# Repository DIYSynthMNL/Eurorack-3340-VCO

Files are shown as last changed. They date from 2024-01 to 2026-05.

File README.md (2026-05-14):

# Eurorack-3340-VCO

A Eurorack VCO module based on the [AS3340](https://electricdruid.net/product/as3340-vco/) chip from Electric Druid — a drop-in clone of the classic Curtis CEM3340. Analog 1V/oct tracking with simultaneous saw, triangle, sine, and pulse outputs.

## Features

- **1V/oct tracking** with two summed V/oct CV inputs (use both for transpose/unison)
- **Course tune** with jumper-selectable range (narrow / wide via JP1) plus **Fine tune** pot
- **Linear FM input** with attenuator pot (Lin FM, ±5V CV)
- **PWM input** with amount attenuator (±5V CV), feeds the chip's pulse-width modulator
- **Hard / Soft Sync** input with panel switch for selection (AC-coupled, 1 nF)
- **Four simultaneous outputs (10 Vpp)**: Saw, Triangle, Sine (diode-shaped from triangle), Pulse
- **Three calibration trims**:
  - Scale trim (RV1) — V/oct gain
  - High-Frequency Tracking trim (RV7) — accuracy at high notes
  - Sine amplitude trim (RV6) — tri-to-sine shape
- **Polystyrene timing capacitor** (C8, 1 nF) for low temperature drift
- Eurorack ±12V power via either 16-pin IDC or 3-pin JST connector

## Inputs and outputs

| Jack | Range | Notes |
|---|---|---|
| V/oct 1 | ±5V | Summed with V/oct 2 at the frequency-control node |
| V/oct 2 | ±5V | Summed with V/oct 1; direct (no attenuator) |
| Lin FM | ±5V | Through RV2 attenuator pot, AC-coupled into chip's Linear FM input |
| PWM | ±5V | Through RV3 amount pot, scaled to ~0–5V into chip's PWM-In |
| Sync | gate/audio | AC-coupled (1 nF), SW1 routes to Hard Sync (down) or Soft Sync (up) |
| Saw Out | 10 Vpp | Buffered, 1K series, ±5V swing |
| Tri Out | 10 Vpp | Buffered, 1K series, ±5V swing |
| Sine Out | 10 Vpp | Diode tri-to-sine shaper, amplitude trim, buffered |
| Pulse Out | 10 Vpp | Buffered, 1K series, ±5V swing |

## Block diagram

```
   V/oct 1 ─┐
   V/oct 2 ─┼──[summing node, 10K + 10K + 47K (course) + 1M5 (fine)]─► AS3340 Freq Control
   Course  ─┤                                                        ├─► Saw    ─► [×2.09 buffer] ─► Saw Out
   Fine ────┘                                                        ├─► Tri    ─► [×2.09 buffer] ─► Tri Out
                                                                     │                          └► [diode shaper + RV6 amp trim] ─► Sine Out
   Lin FM ─► [×RV2 amount] ─► [bias network: 1M5/+12V, 470R/GND] ──► AS3340 Lin FM In           
                                                                     │
   PWM CV ─► [×RV3 amount + 100K/200K/100K conditioner] ───────────► AS3340 PWM In ◄─── [10K hysteresis from Pulse Out]
                                                                     │
   Sync in ─► [1 nF AC-couple] ─► SW1 ─► Hard Sync / Soft Sync ────► AS3340 Sync
                                                                     │
                                                                     └─► Pulse  ─► [×2.09 buffer] ─► Pulse Out

   Calibration trims:
     RV1 (Scale)  → AS3340 Scale1/Scale2 pins (V/oct gain)
     RV7 (HFT)    → AS3340 HFT pin (high-frequency correction)
     RV6 (Sine Amp) → tri-to-sine output buffer (sine amplitude)

   Eurorack ±12V ─► U3 (78M05) / U4 (79M05) ─► ±5V rails (op-amp + chip VEE)
   Timing cap: C8 = 1 nF polystyrene (critical: do not substitute ceramic)
```

## Power

- Eurorack ±12V via **J10** (3-pin JST) or **J11** (16-pin IDC) — populate one
- Local U3 (78M05) makes +5V from +12V
- Local U4 (79M05) makes −5V from −12V; this becomes the AS3340's VEE pin voltage
- R39 / R40 (10K) are optional minimum-load resistors
- D3 / D4 — reverse-polarity protection diodes

**AS3340 VEE protection.** The chip has an internal 7.4V Zener; the absolute max for VEE-to-GND is −6V. Because VEE here is driven from −5V (not −12V directly), no current-limiting resistor (REE) is needed.

If you ever modify the design to feed VEE directly from a more-negative rail, the datasheet formula is **REE = (|VEE| − 7.4) / 0.008**:

| VEE supply | REE |
|---|---|
| −5V | none |
| −12V | ~575 Ω |
| −15V | ~950 Ω (820 Ω works) |

## Calibration

The board has three trim pots that interact. Adjust in this order. You'll need: a multimeter, a frequency counter or tuner (a phone tuner app works), and a stable temperature environment (let the module warm up ~10 minutes first — the chip drifts thermally during warm-up).

**Step 1 — Scale trim (RV1).** Sets the V/oct gain. This is the most important trim for musical accuracy.

1. With no CV patched and Course/Fine at 12 o'clock, note the output frequency.
2. Patch a known reference voltage into V/oct 1 (e.g., 0V from a calibrated source or shorted to GND). Tune Course/Fine until the saw output matches a reference note — say C2 (65.41 Hz).
3. Apply +1V to V/oct 1. The output should rise exactly one octave (C3 = 130.81 Hz). If it's high, lower RV1 slightly; if low, raise it.
4. Step the input voltage up to +4V or +5V and verify the output is still tracking 1V/oct. Iterate RV1 + the tune knob until accurate across 5+ octaves.

**Step 2 — High-Frequency Tracking trim (RV7).** Compensates for internal comparator delay at very high notes.

1. With the V/oct calibrated (Step 1), apply +6V or +7V to push the output to ~8 kHz+.
2. Compare actual output frequency to expected (e.g., from 65.41 Hz baseline, +7 octaves = 8372 Hz).
3. Adjust RV7 to correct the deviation. RV7 mostly affects high frequencies — it should not noticeably shift low-frequency tuning.
4. Re-verify Step 1 calibration. If low-frequency tracking shifted, iterate.

**Step 3 — Sine Amplitude trim (RV6).** Sets the tri-to-sine shape and amplitude.

1. Patch a scope on the Sine Out jack with a steady tone (e.g., A4 = 440 Hz).
2. Adjust RV6 until the waveform looks like a clean sine — not too peaked (under-trimmed) and not flat-topped (over-trimmed).
3. By ear: clean smooth fundamental, no harsh harmonics.

## References

Local archived copies live in [`references/`](references/) so this repo stays useful if the upstream links die.

- **AS3340 datasheet** — [local copy](references/AS3340-alfatriode-2020.pdf) · [upstream (alfatriode.lv)](https://alfatriode.lv/eng/sc/AS3340.pdf)
- **Kassutronics 3340 VCO docs (v2.4)** — [local copy](references/Kassutronics-VCO3340-docs-v2.4.pdf) · [upstream (GitHub)](https://github.com/kassu/kassutronics/tree/master/documentation/VCO%203340) — primary design inspiration
- [Electric Druid AS3340 product page](https://electricdruid.net/product/as3340-vco/)
- [Electric Druid CEM3340 VCO designs](https://electricdruid.net/cem3340-vco-voltage-controlled-oscillator-designs/)
- [YuSynth VCO](https://yusynth.net/Modular/EN/VCO/index.html)
- [Tri-to-sine shaping techniques (Tim Stinchcombe)](https://www.timstinchcombe.co.uk/index.php?pge=trisin)

## Build status

What's ready for builders today, and what's still on the TODO list:

**Production assets** (what you need to actually fabricate and assemble a final unit)

- [x] Schematic — Rev 0.1.2 ([PDF](Schematic%20PDFs/3340-VCO-Schematic-Rev0.1.2.pdf))
- [ ] PCB layout — in progress — single working layout in `kicad/`, not yet separated for fab. The current rev is labeled "Prototype."
- [ ] Gerber files for fabrication — none yet
- [x] BOM — [Rev 0.1.0 PDF](BOMs/BOMs%20-%203340%20VCO%20-%20Schematic%20Rev%200.1.0.pdf) *(critical: use polystyrene for C8 timing cap, not ceramic)*
- [ ] Final front panel (SVG/PDF for fab) — none yet
- [ ] License — none yet

**Prototype assets** (for breadboard / perfboard / 3D-printed-panel builds before final PCB)

- [x] 3D-printed prototype panel STL — [3340_VCO.stl](3D%20printed%20front%20panel/3340_VCO.stl)
- [x] Falstad simulations of sub-circuits — [falstad/](falstad/)

**Documentation**

- [ ] Photos of the assembled module — none yet (drop in [`photos/`](photos/))
- [ ] Demo video — none yet
- [ ] Build / assembly instructions — none yet
- [x] Calibration / tuning notes — see "Calibration" section above

Want to help fill a gap (build photos, gerbers, an assembly guide)? Open an issue or PR.

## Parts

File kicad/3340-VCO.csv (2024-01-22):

Source: | C:\Users\Acer\Desktop\Synth DIY\KiCad Designs\VCOs\3340-VCO\kicad\3340-VCO.kicad_sch
Date: | 21/01/2024 8:39:00 pm
Tool: | Eeschema 7.0.9
Generator: | C:\Program Files\KiCad\7.0\bin\scripting\plugins/bom_csv_grouped_by_value.py
Component Count: | 78
Collated Components:
Item | Qty | Reference(s) | Value | LibPart | Footprint | Datasheet | DNP | Sim.Device | Sim.Pins
1 | 3 | C1, C7, C9 | 100nF | Device:C | DIYSynthMNL:C_Rect_L7.0mm_W2.0mm_P5.00mm_BigPads | ~
2 | 3 | C2, C3, C15 | 100nF | Device:C |  | ~
3 | 4 | C5, C6, C8, C10 | 2.2uF | Device:C_Polarized | DIYSynthMNL:CP_Radial_D5.0mm_P2.50mm | ~
4 | 2 | C11, C12 | 22uF | Device:C_Polarized | DIYSynthMNL:CP_Radial_D4.0mm_P1.50mm | ~
5 | 1 | C13 | 1nF_Polystyrene | Device:C |  | ~
6 | 2 | C14, C16 | 10nF | Device:C |  | ~
7 | 1 | C17 | 1nF | Device:C |  | ~
8 | 3 | C18, C19, C20 | 10pF | Device:C |  | ~
9 | 2 | D1, D2 | ~ | Device:D | DIYSynthMNL:D_DO-41_SOD81_P7.62mm_Horizontal_BigPads | ~ |  | D | 1=K 2=A
10 | 2 | D3, D4 | 4148 | Device:D |  | ~ |  | D | 1=K 2=A
11 | 1 | J1 | EuroPower_JST_3P | DIYSynthMNL:JST_Eurorack_power_3P | DIYSynthMNL:Eurorack_power_jst_3P
12 | 1 | J2 | EURO_PWR_16P | DIYSynthMNL:EURO_PWR_16_PIN | DIYSynthMNL:IDC-Header_2x08_P2.54mm_Vertical
13 | 1 | JP1 | Course_tune_gnd | Jumper:Jumper_2_Open |  | ~
14 | 1 | JP2 | Course_tune_-5V | Jumper:Jumper_2_Open |  | ~
15 | 2 | R1, R2 | *10K | Device:R | DIYSynthMNL:R_quarter_watt_L6.3mm_D2.5mm_P7.62mm | ~
16 | 1 | R3 | 24K | Device:R |  | ~
17 | 1 | R4 | 5K6 | Device:R |  | ~
18 | 1 | R5 | 1K8 | Device:R |  | ~
19 | 2 | R6, R14 | 1M5 | Device:R |  | ~
20 | 2 | R7, R10 | 470R | Device:R |  | ~
21 | 1 | R8 | 1M | Device:R |  | ~
22 | 1 | R9 | 220K | Device:R |  | ~
23 | 10 | R11, R12, R16, R19, R21, R22, R24, R28, R33, R34 | 100K | Device:R |  | ~
24 | 1 | R13 | 47K | Device:R |  | ~
25 | 1 | R15 | 470K | Device:R |  | ~
26 | 1 | R17 | 200K | Device:R |  | ~
27 | 5 | R18, R26, R27, R32, R40 | 1K | Device:R |  | ~
28 | 1 | R20 | 10M | Device:R |  | ~
29 | 3 | R23, R30, R36 | 91K | Device:R |  | ~
30 | 3 | R25, R29, R35 | 240K | Device:R |  | ~
31 | 1 | R31 | 180K | Device:R |  | ~
32 | 1 | R37 | 15K | Device:R |  | ~
33 | 1 | R38 | 22K | Device:R |  | ~
34 | 1 | R39 | 150K | Device:R |  | ~
35 | 2 | RV1, RV4 | 10K | Device:R_Potentiometer_Trim |  | ~
36 | 3 | RV2, RV3, RV5 | 100K | Device:R_Potentiometer |  | ~
37 | 1 | RV6 | 2K | Device:R_Potentiometer_Trim |  | ~
38 | 1 | SW1 | SW_SPDT | Switch:SW_SPDT |  | ~
39 | 1 | U1 | AS3340 | DIYSynthMNL:A3340
40 | 1 | U2 | TL074 | Amplifier_Operational:TL074 |  | http://www.ti.com/lit/ds/symlink/tl071.pdf
41 | 1 | U6 | 78M05 | Regulator_Linear:LM78M05_TO252 | Package_TO_SOT_SMD:TO-252-2 | https://www.onsemi.com/pub/Collateral/MC78M00-D.PDF
42 | 1 | U7 | 79M05 | Regulator_Linear:MC79M05_TO252 | Package_TO_SOT_SMD:TO-252-2 | http://www.onsemi.com/pub/Collateral/MC79M00-D.PDF

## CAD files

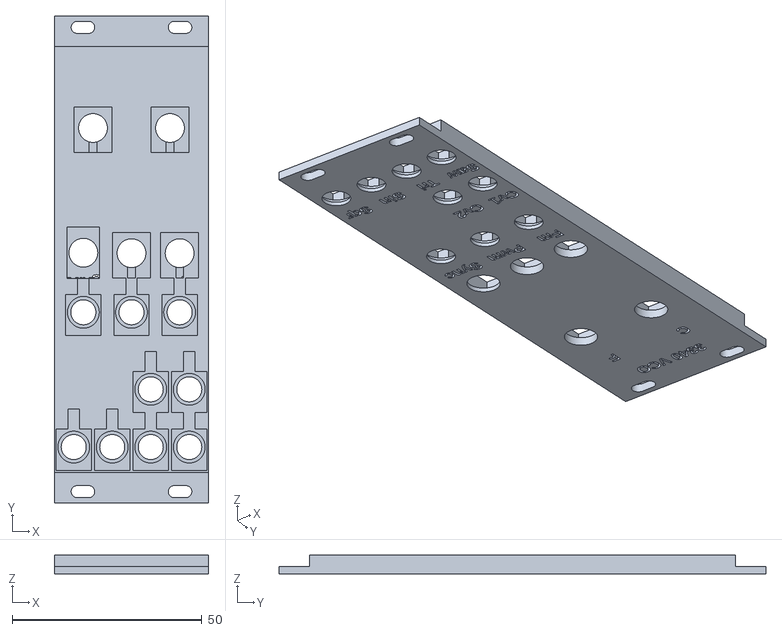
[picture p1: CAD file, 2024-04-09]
3D printed front panel/3340_VCO.stl
40.6 x 128.5 x 5.00

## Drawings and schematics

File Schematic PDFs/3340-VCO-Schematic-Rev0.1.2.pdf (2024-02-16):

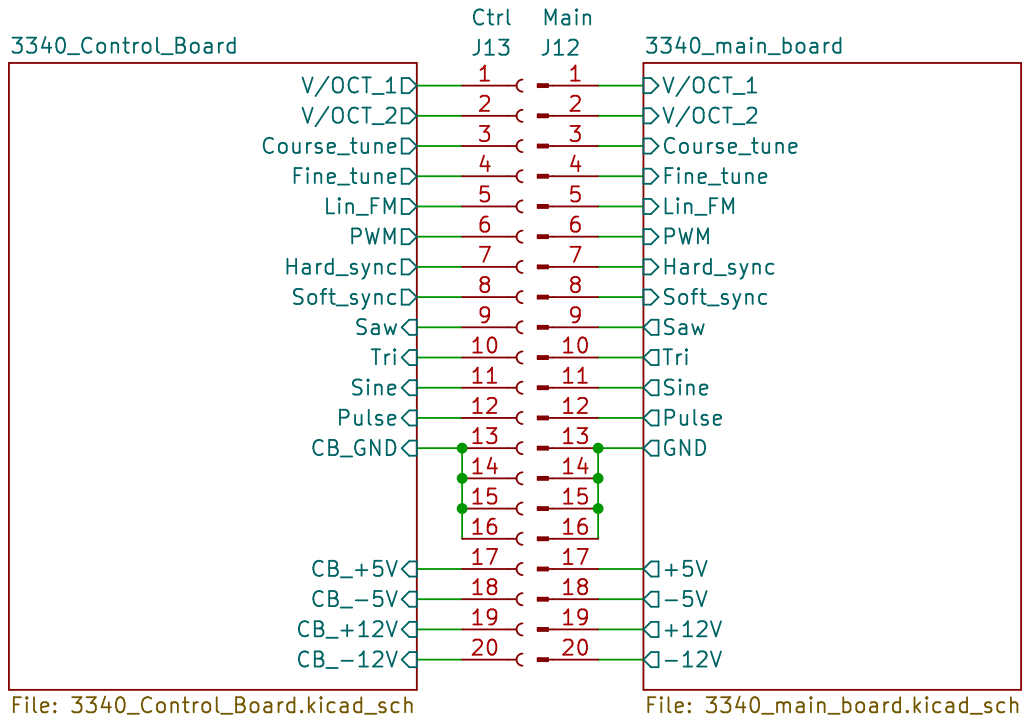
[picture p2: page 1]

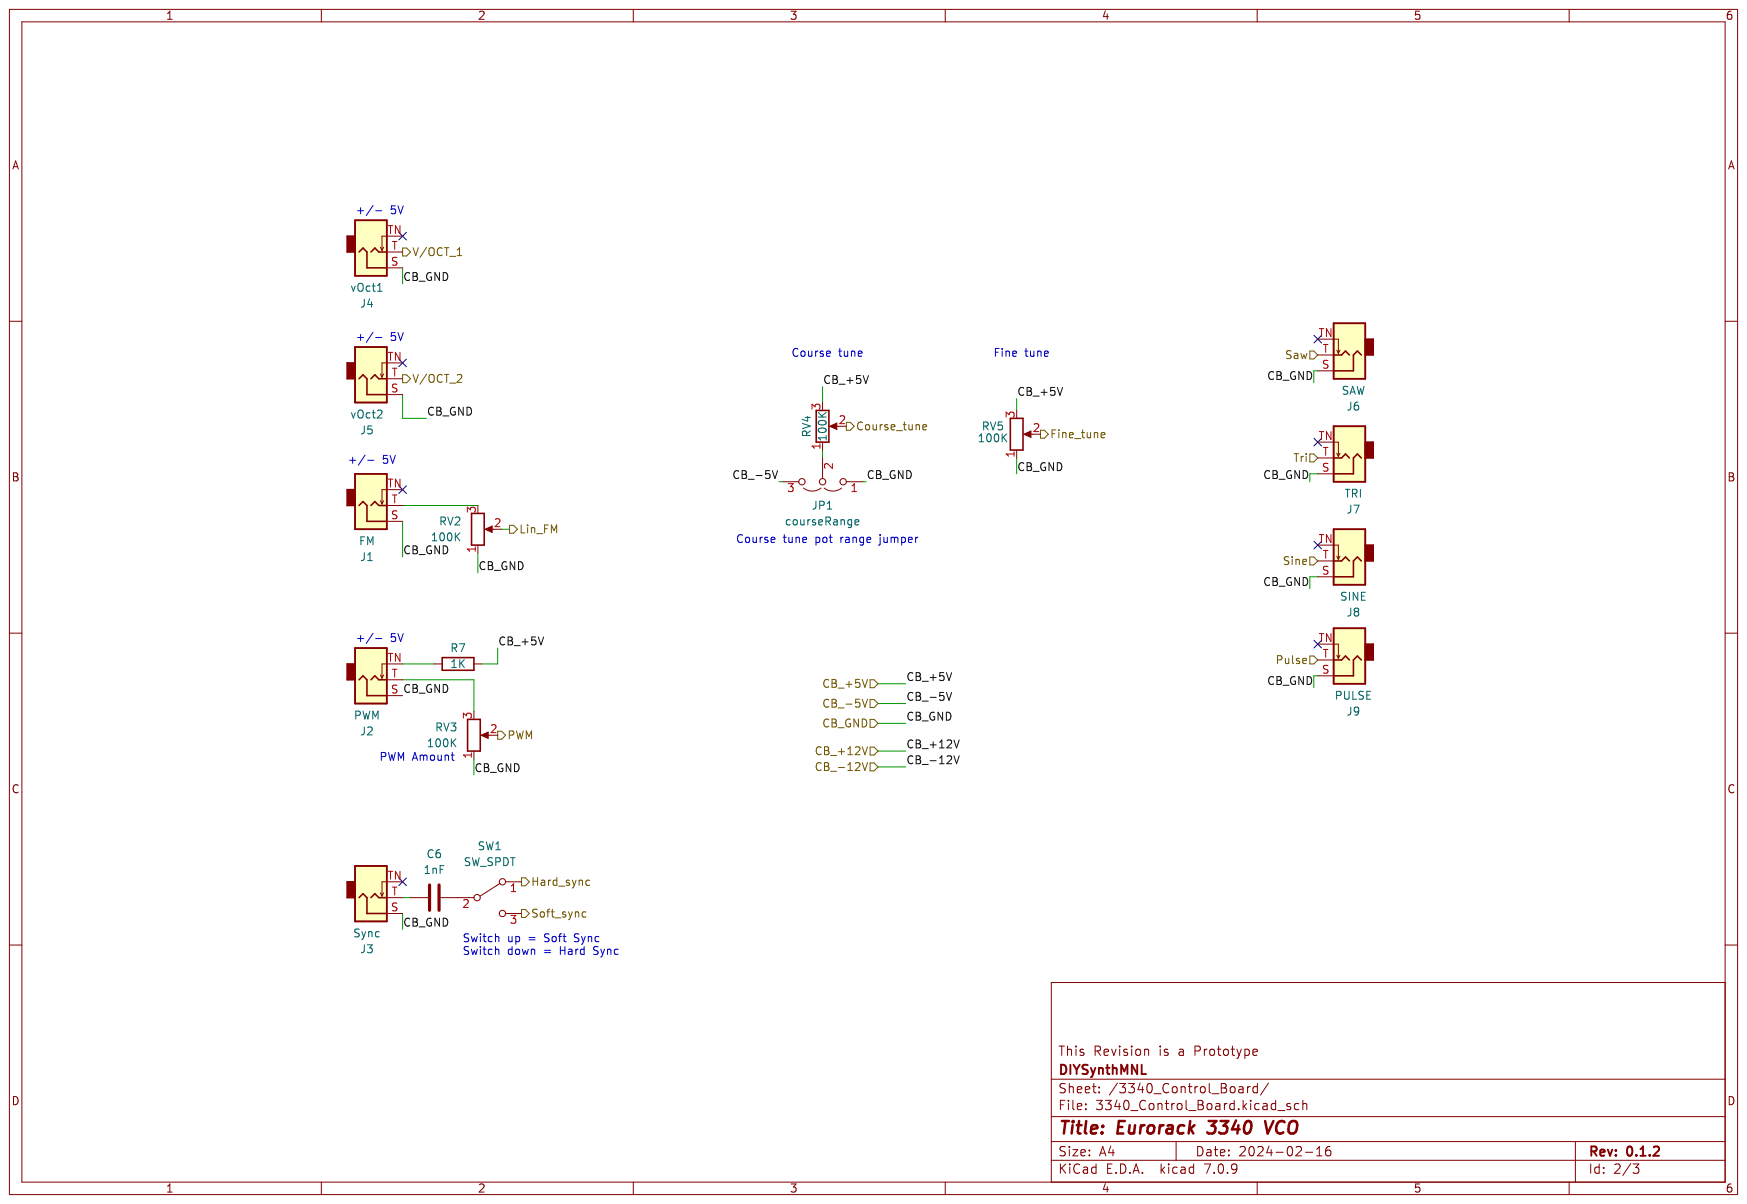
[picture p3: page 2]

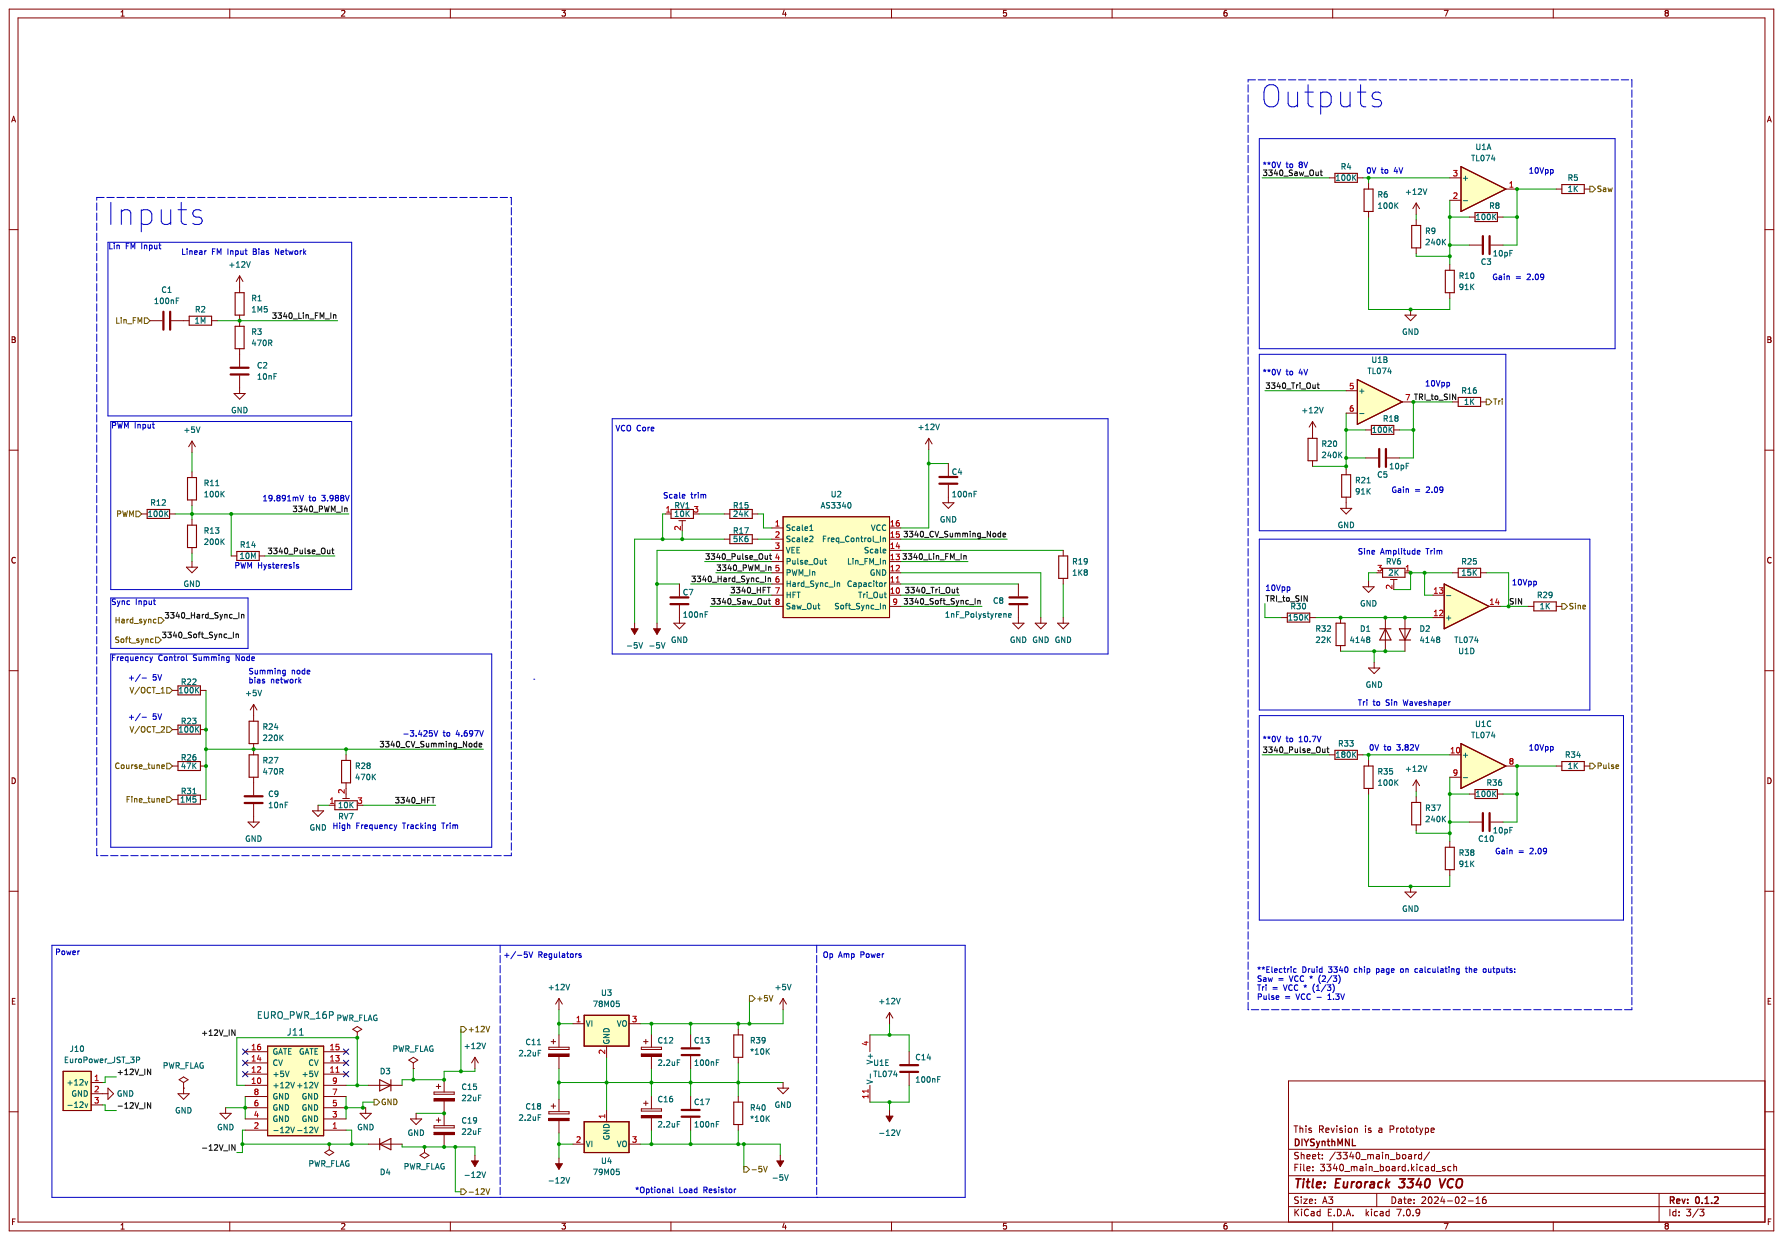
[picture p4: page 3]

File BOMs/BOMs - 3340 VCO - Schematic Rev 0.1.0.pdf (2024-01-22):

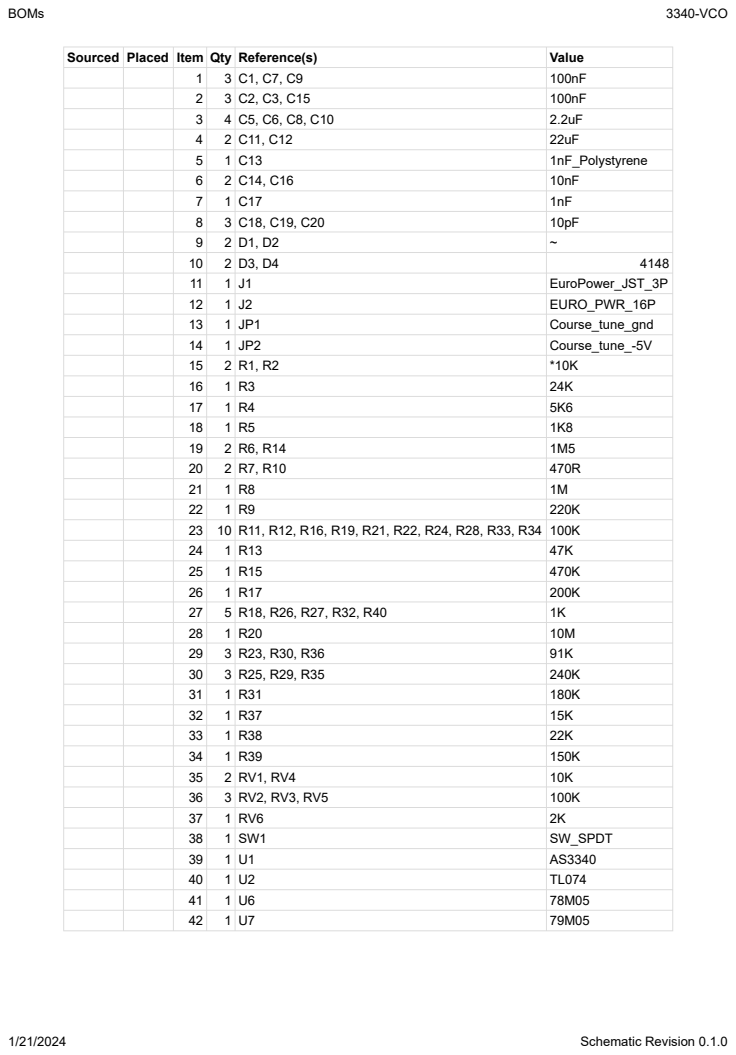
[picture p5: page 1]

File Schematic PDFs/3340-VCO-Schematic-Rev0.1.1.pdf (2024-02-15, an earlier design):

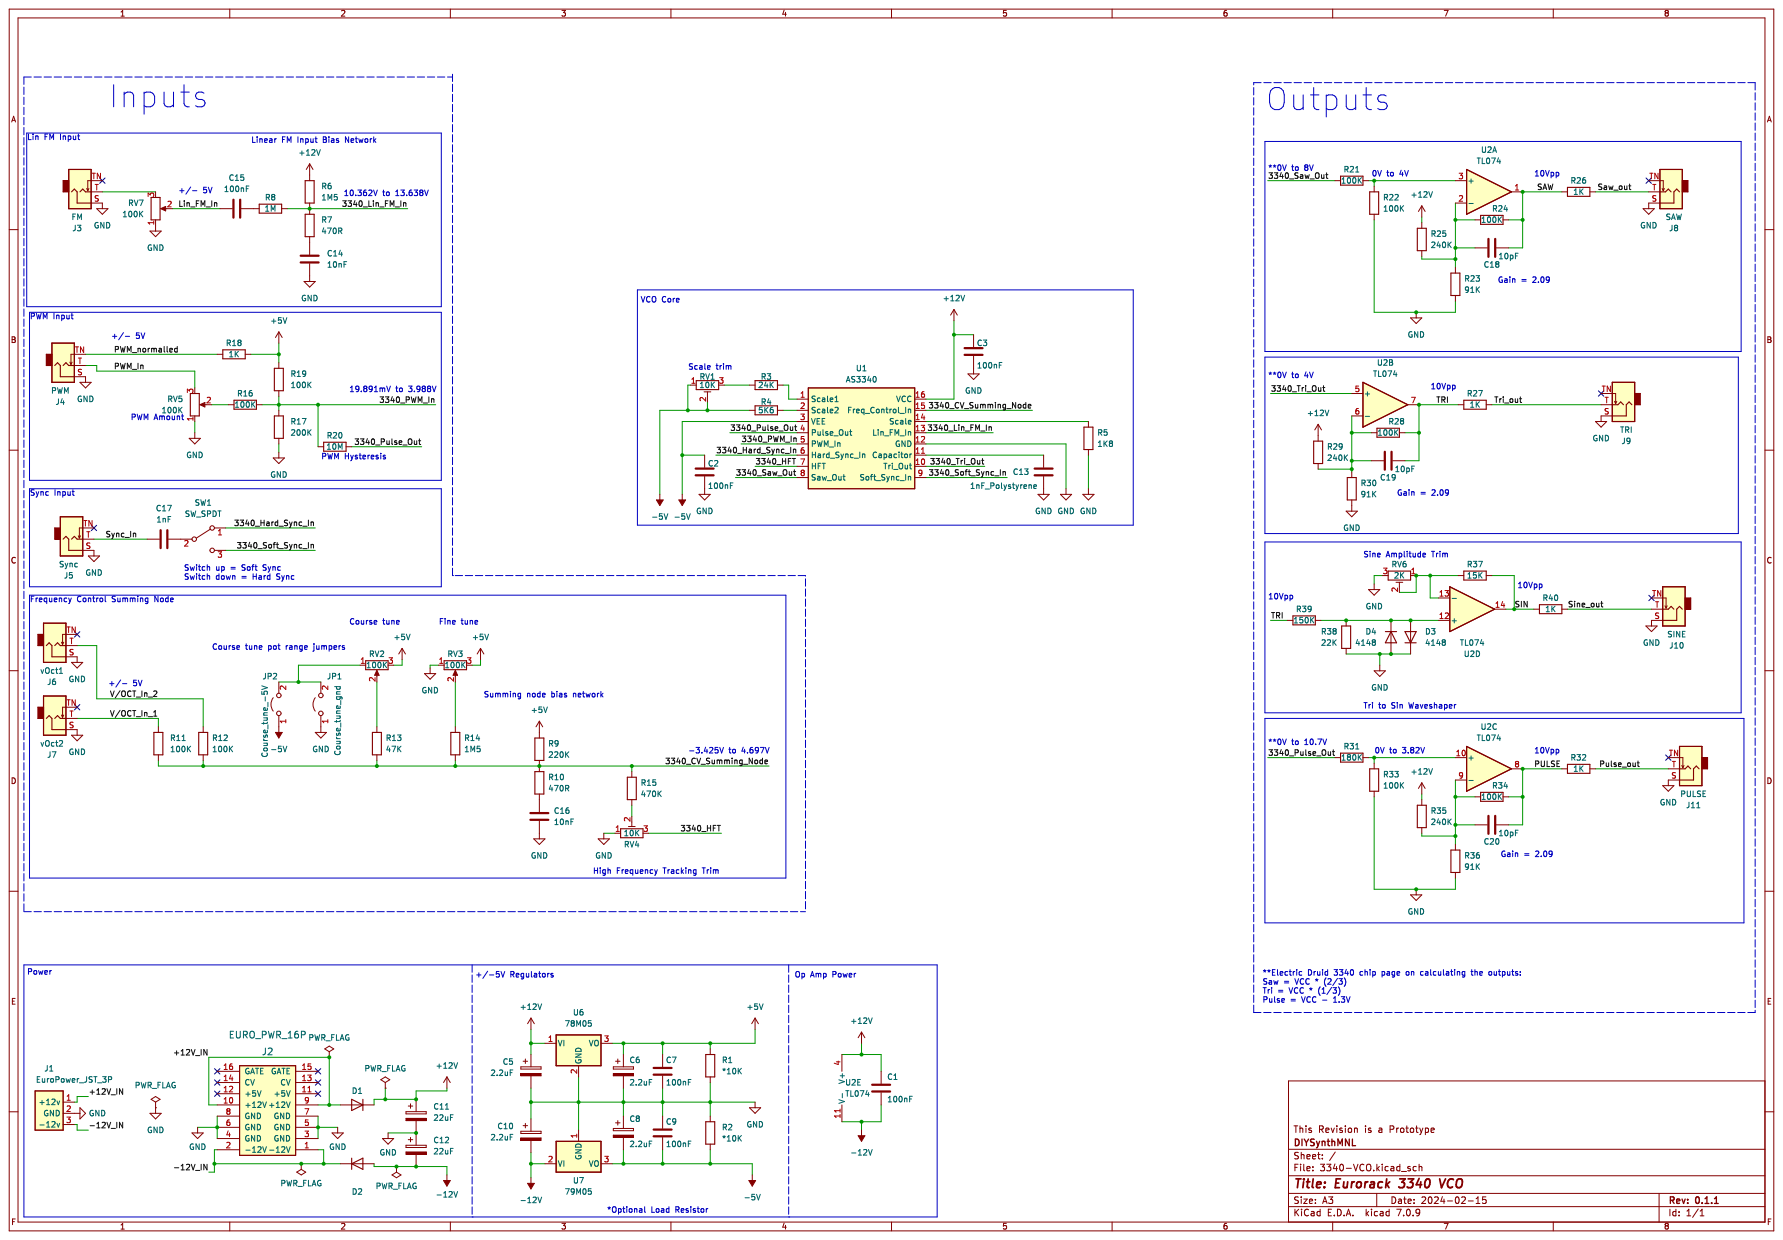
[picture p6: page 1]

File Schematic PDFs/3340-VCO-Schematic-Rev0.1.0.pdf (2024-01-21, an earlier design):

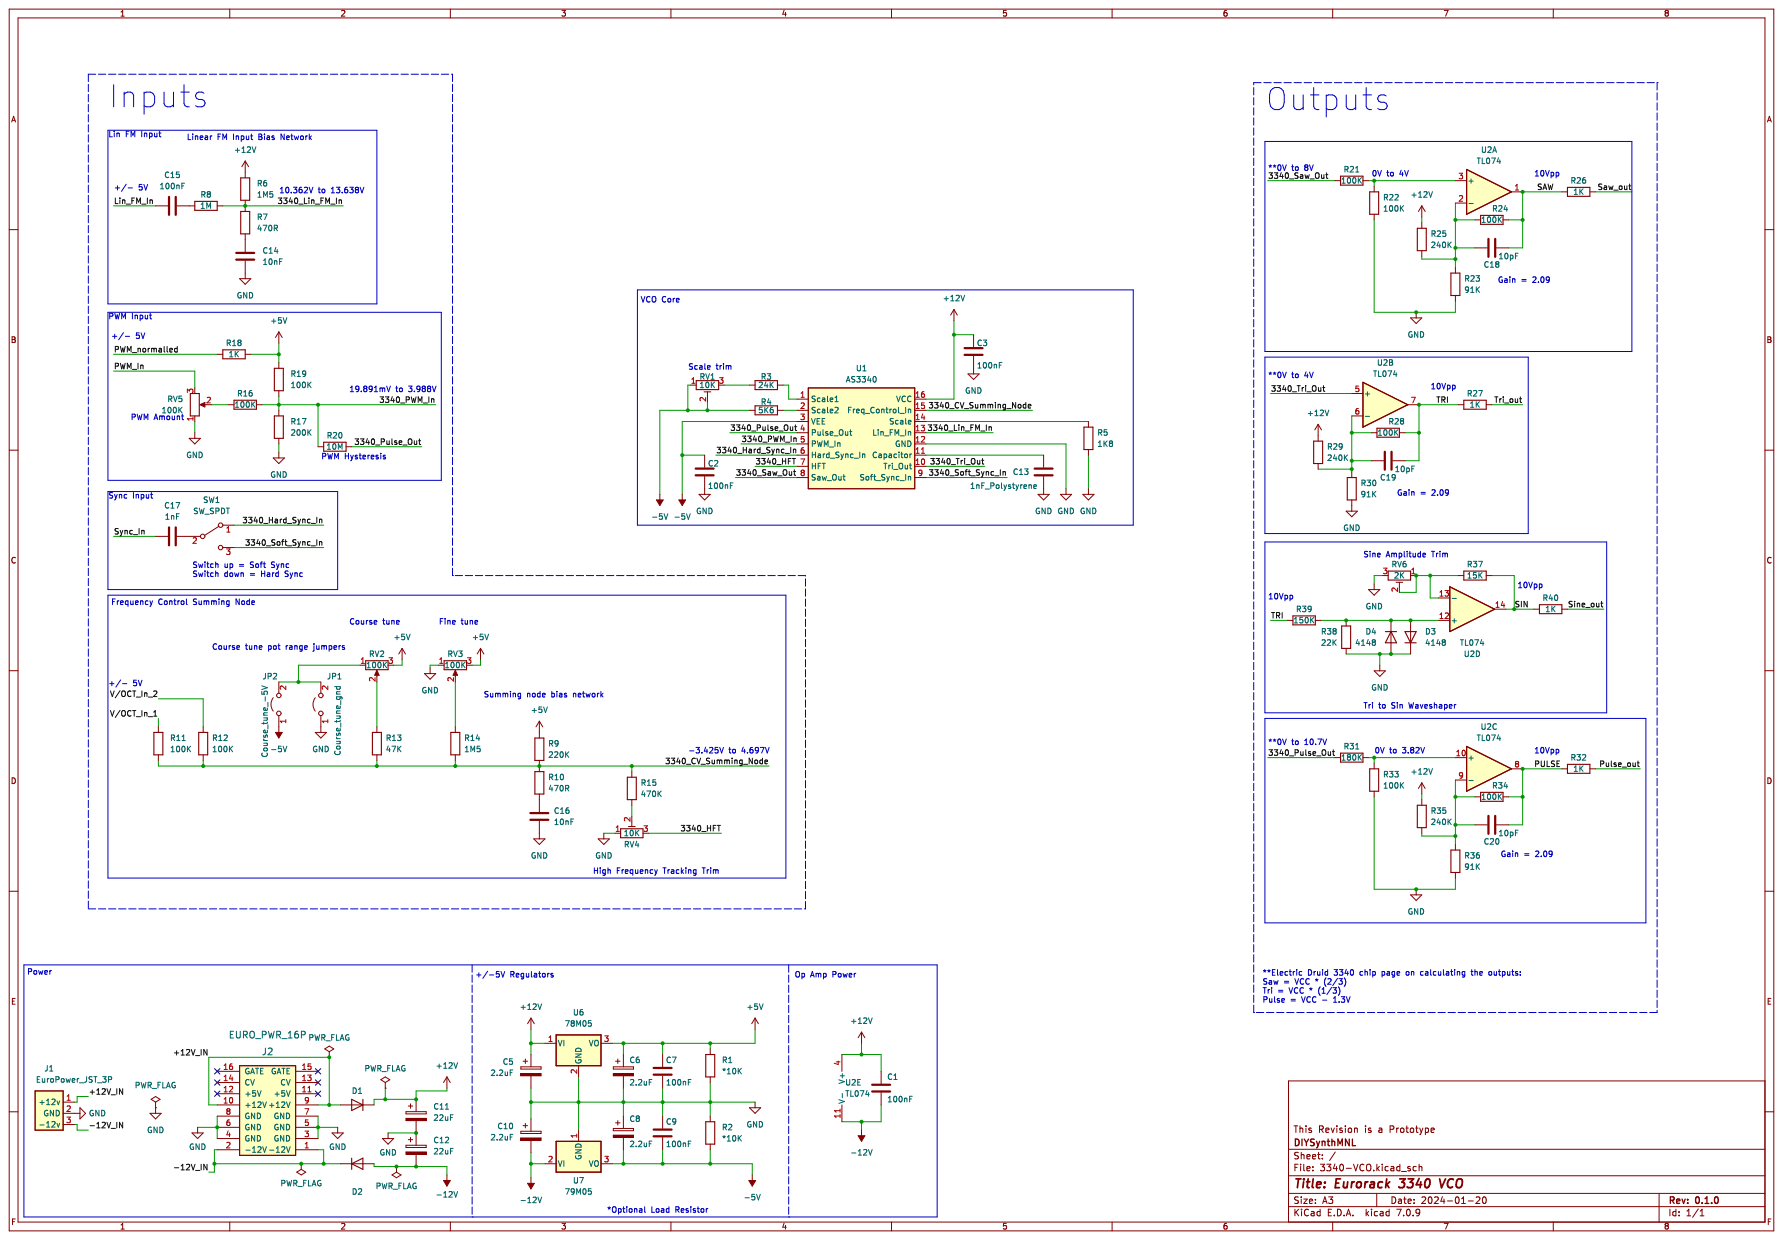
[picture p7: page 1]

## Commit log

2024-01-20 folder update
    [3340-VCO.kicad_pcb, 3340-VCO.kicad_sch]
2024-01-21 Schematic rev 0.1.0 updated
    [3340-VCO.kicad_sch]
2024-01-22 added schematic rev 0.1.0 bom
    [3340-VCO.csv]
2024-01-22 added kicad gitignore
2024-02-15 added schem 0.1.1
    [3340-VCO.kicad_sch]
2024-02-16 added multiboard schematic (rev 0.1.2)
    [3340-VCO.kicad_sch, 3340_Control_Board.kicad_sch, 3340_main_board.kicad_sch]
2024-02-16 assigned through hole footprints
    [3340-VCO.kicad_sch, 3340_Control_Board.kicad_sch, 3340_main_board.kicad_sch]
2026-05-14 Fix Build status link path case
2026-05-14 Add photos/ placeholder for assembled-module shots
2026-05-14 Expand README with features, I/O table, block diagram, calibration procedure
